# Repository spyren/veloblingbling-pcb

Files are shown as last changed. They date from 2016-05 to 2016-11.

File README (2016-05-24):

Electronic Design for the Velo Bling-Bling Project
**************************************************

http://veloblingbling.ch

LED lights for bicycle wheels.
16 multi color LEDs on each side (PCB top- and bottom side).
There are two windows (upper and lower) on each side for display dynamic
information like speed, trip time, trip distance, etc. or static information
like strings and images.

The Printed Circuit Board (PCB) is free hardware.
The PCB is a multi-layer (4 layer) 160 x 30.5 x 1.6 mm FR4 board.
The firmware for the MK22DX256VLF5 MCU is also on GitHub:
https://github.com/spyren/veloblingbling-mcu

There is also an optional Bluetooth Low Energy (Smart) subsystem on board.
It is a LAIRD BL600-SA module. The Bluetooth application software is on GitHub
too:
https://github.com/spyren/veloblingbling-ble

It is possible to mount die PCB direct onto the wheel spokes but it is better
to use a mounting frame. This frame can be ordered from http://shapeways.com
or you can print it by yourself on 3D printer.
https://github.com/spyren/veloblingbling-frame

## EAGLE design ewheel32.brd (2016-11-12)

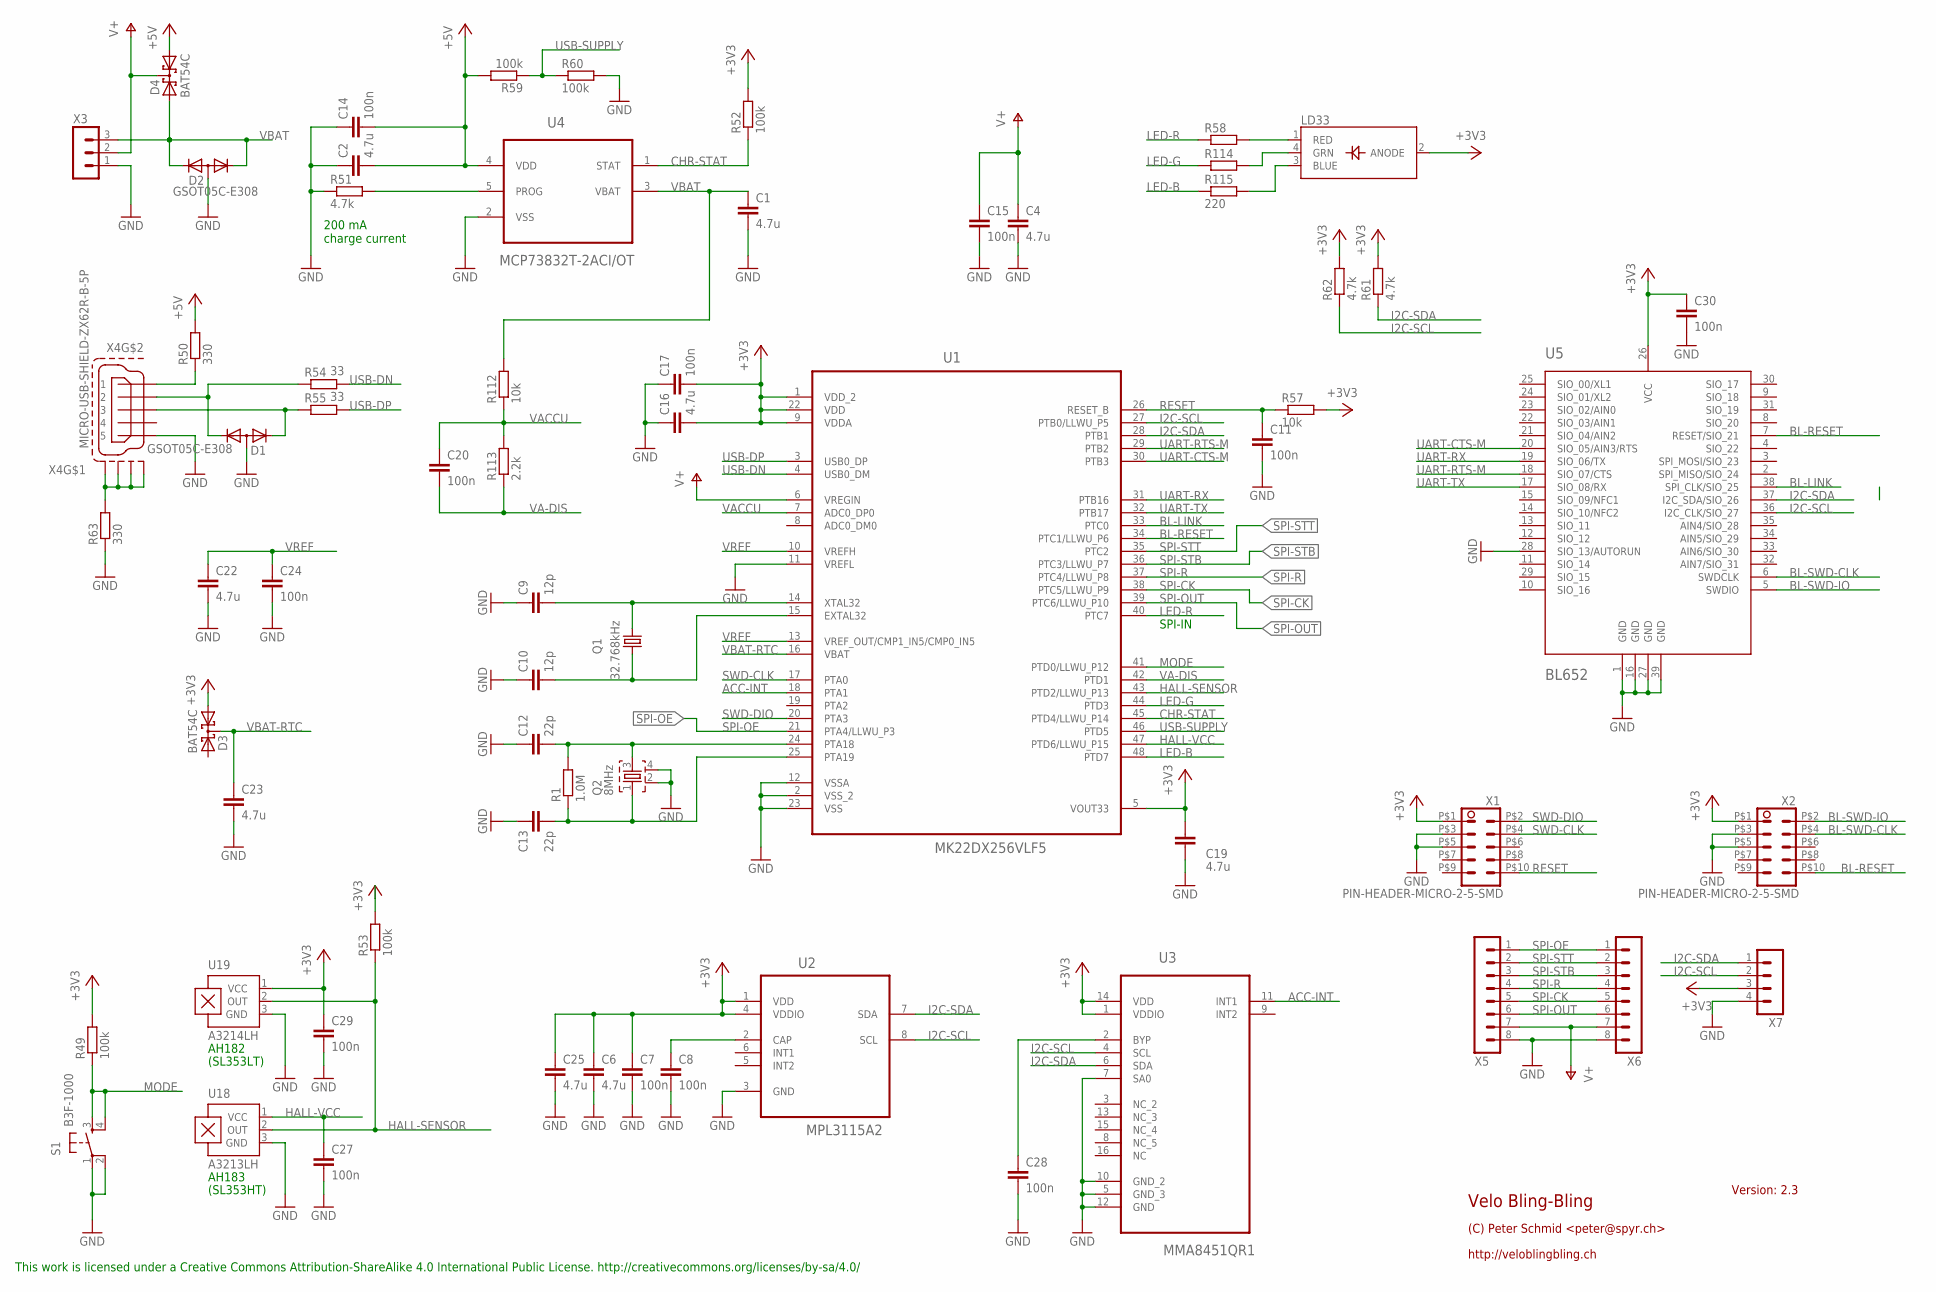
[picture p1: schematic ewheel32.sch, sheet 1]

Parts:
C1, C2, C4, C6, C16, C19, C22, C23, C25: 4.7u; C0805
C7, C8, C11, C14, C15, C17, C20, C24, C27, C28, C29, C30: 100n; C0805
C9, C10: 12p; C0805
C12, C13: 22p; C0805
D1, D2: GSOT05C-E308; SOT23
D3, D4: BAT54C; SOT23
LD33: CLV1A-FKB; RGBLED-PLCC4
Q1: 32.768kHz; ABS07
Q2: 8MHz; ABM3B
R1: 1.0M; R0805
R49, R52, R53, R59, R60: 100k; R0805
R50, R63: 330; R1206
R51, R61, R62: 4.7k; R0805
R54, R55: 33; R0805
R57, R112: 10k; R0805
R58, R114, R115: 220; R0805
R113: 2.2k; R0805
S1: B3F-1000; B3S-1000
U1: MK22DX256VLF5; QFP50P900X900X160-48N
U2: MPL3115A2; DFN300X500X120-8N
U3: MMA8451QR1; QFN50P300X300X100-16N
U4: MCP73832T-2ACI/OT; SOT95P280X145-5N
U5: BL652
U18: A3213LH; SOT23-W
U19: A3214LH; SOT23-W
X1, X2: PIN-HEADER-MICRO-2-5-SMD; PIN-HEADER-NICRO-2-5-SMD
X3: MA03-1
X4: MICRO-USB-SHIELD-ZX62R-B-5P; ZX62R-B-5P
X5, X6: MA08-1
X7: MA04-1

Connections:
+3V3: C6.1, C7.1, C16.2, C17.2, C19.1, C25.1, C29.1, C30.1, D3.1 (A1), LD33.2 (ANODE), R49.2, R52.2, R53.2, R57.2, R61.2, R62.2, U1.1 (VDD_2), U1.5 (VOUT33), U1.9 (VDDA), U1.22 (VDD), U2.1 (VDD), U2.4 (VDDIO), U3.1 (VDDIO), U3.14 (VDD), U5.26 (VCC), U19.1 (VCC), X1.P$1 (1), X2.P$1 (1), X7.3
+5V: C2.2, C14.2, D4.1 (A1), R50.2, R59.2, U4.4 (VDD)
ACC-INT: U1.18 (PTA1), U3.11 (INT1)
BL-LINK: U1.33 (PTC0), U5.38 (SPI_CLK/SIO_25)
BL-RESET: U1.34 (PTC1/LLWU_P6), U5.7 (RESET/SIO_21), X2.P$10 (10)
BL-SWD-CLK: U5.6 (SWDCLK), X2.P$4 (4)
BL-SWD-IO: U5.5 (SWDIO), X2.P$2 (2)
CHR-STAT: R52.1, U1.45 (PTD4/LLWU_P14), U4.1 (STAT)
GND: C1.2, C2.1, C4.2, C6.2, C7.2, C8.2, C9.1, C10.1, C11.2, C12.1, C13.1, C14.1, C15.2, C16.1, C17.1, C19.2, C22.2, C23.2, C24.2, C25.2, C27.2, C28.2, C29.2, C30.2, D1.3 (A), D2.3 (A), Q2.2, Q2.4, R51.1, R60.2, R63.1, S1.1, S1.2 (P1), U1.2 (VSS_2), U1.11 (VREFL), U1.12 (VSSA), U1.23 (VSS), U2.3 (GND), U3.5 (GND_3), U3.7 (SA0), U3.10 (GND_2), U3.12 (GND), U4.2 (VSS), U5.1 (GND), U5.16 (GND), U5.27 (GND), U5.28 (SIO_13/AUTORUN), U5.39 (GND), U18.3 (GND), U19.3 (GND), X1.P$3 (3), X1.P$5 (5), X2.P$3 (3), X2.P$5 (5), X3.1, X4.5, X5.8, X6.8, X7.4; also elsewhere on the board
HALL-SENSOR: R53.1, U1.43 (PTD2/LLWU_P13), U18.2 (OUT), U19.2 (OUT)
HALL-VCC: C27.1, U1.47 (PTD6/LLWU_P15), U18.1 (VCC)
I2C-SCL: R62.1, U1.27 (PTB0/LLWU_P5), U2.8 (SCL), U3.4 (SCL), U5.36 (I2C_CLK/SIO_27), X7.2
I2C-SDA: R61.1, U1.28 (PTB1), U2.7 (SDA), U3.6 (SDA), U5.37 (I2C_SDA/SIO_26), X7.1
LED-B: R115.1, U1.48 (PTD7)
LED-G: R114.1, U1.44 (PTD3)
LED-R: R58.1, U1.40 (PTC7)
MODE: R49.1, S1.3 (S), S1.4 (S1), U1.41 (PTD0/LLWU_P12)
unnamed: C12.2, Q2.3, R1.2, U1.24 (PTA18)
unnamed: C13.2, Q2.1, R1.1, U1.25 (PTA19)
unnamed: C28.1, U3.2 (BYP)
unnamed: R51.2, U4.5 (PROG)
unnamed: LD33.4 (GRN), R114.2
unnamed: LD33.1 (RED), R58.2
unnamed: LD33.3 (BLUE), R115.2
unnamed: R63.2, X4.M1 (S1), X4.M2 (S2), X4.M3 (S3), X4.M4 (S4)
unnamed: C8.1, U2.2 (CAP)
unnamed: R50.1, X4.1
unnamed: D1.1 (K1), R54.1, X4.2
unnamed: D1.2 (K2), R55.1, X4.3
unnamed: C9.2, Q1.P$2 (2), U1.14 (XTAL32)
unnamed: C10.2, Q1.P$1 (1), U1.15 (EXTAL32)
RESET: C11.1, R57.1, U1.26 (RESET_B), X1.P$10 (10)
SPI-CK: U1.38 (PTC5/LLWU_P9), X5.5, X6.5; also elsewhere on the board
SPI-OE: U1.21 (PTA4/LLWU_P3), X5.1, X6.1; also elsewhere on the board
SPI-OUT: U1.39 (PTC6/LLWU_P10), X5.6, X6.6; also elsewhere on the board
SPI-R: U1.37 (PTC4/LLWU_P8), X5.4, X6.4; also elsewhere on the board
SPI-STB: U1.36 (PTC3/LLWU_P7), X5.3, X6.3; also elsewhere on the board
SPI-STT: U1.35 (PTC2), X5.2, X6.2; also elsewhere on the board
SWD-CLK: U1.17 (PTA0), X1.P$4 (4)
SWD-DIO: U1.20 (PTA3), X1.P$2 (2)
UART-CTS-M: U1.30 (PTB3), U5.20 (SIO_05/AIN3/RTS)
UART-RTS-M: U1.29 (PTB2), U5.18 (SIO_07/CTS)
UART-RX: U1.31 (PTB16), U5.19 (SIO_06/TX)
UART-TX: U1.32 (PTB17), U5.17 (SIO_08/RX)
USB-DN: R54.2, U1.4 (USB0_DM)
USB-DP: R55.2, U1.3 (USB0_DP)
USB-SUPPLY: R59.1, R60.1, U1.46 (PTD5)
V+: C4.1, C15.1, D4.3 (CC), U1.6 (VREGIN), X3.2, X5.7, X6.7; also elsewhere on the board
VA-DIS: C20.2, R113.1, U1.42 (PTD1)
VACCU: C20.1, R112.1, R113.2, U1.7 (ADC0_DP0)
VBAT: C1.1, D2.1 (K1), D2.2 (K2), D4.2 (A2), R112.2, U4.3 (VBAT), X3.3
VBAT-RTC: C23.1, D3.3 (CC), U1.16 (VBAT)
VREF: C22.1, C24.1, U1.10 (VREFH), U1.13 (VREF_OUT/CMP1_IN5/CMP0_IN5)

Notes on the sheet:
200 mA charge current
SPI-IN
(SL353LT)
(SL353HT)
AH182
AH183

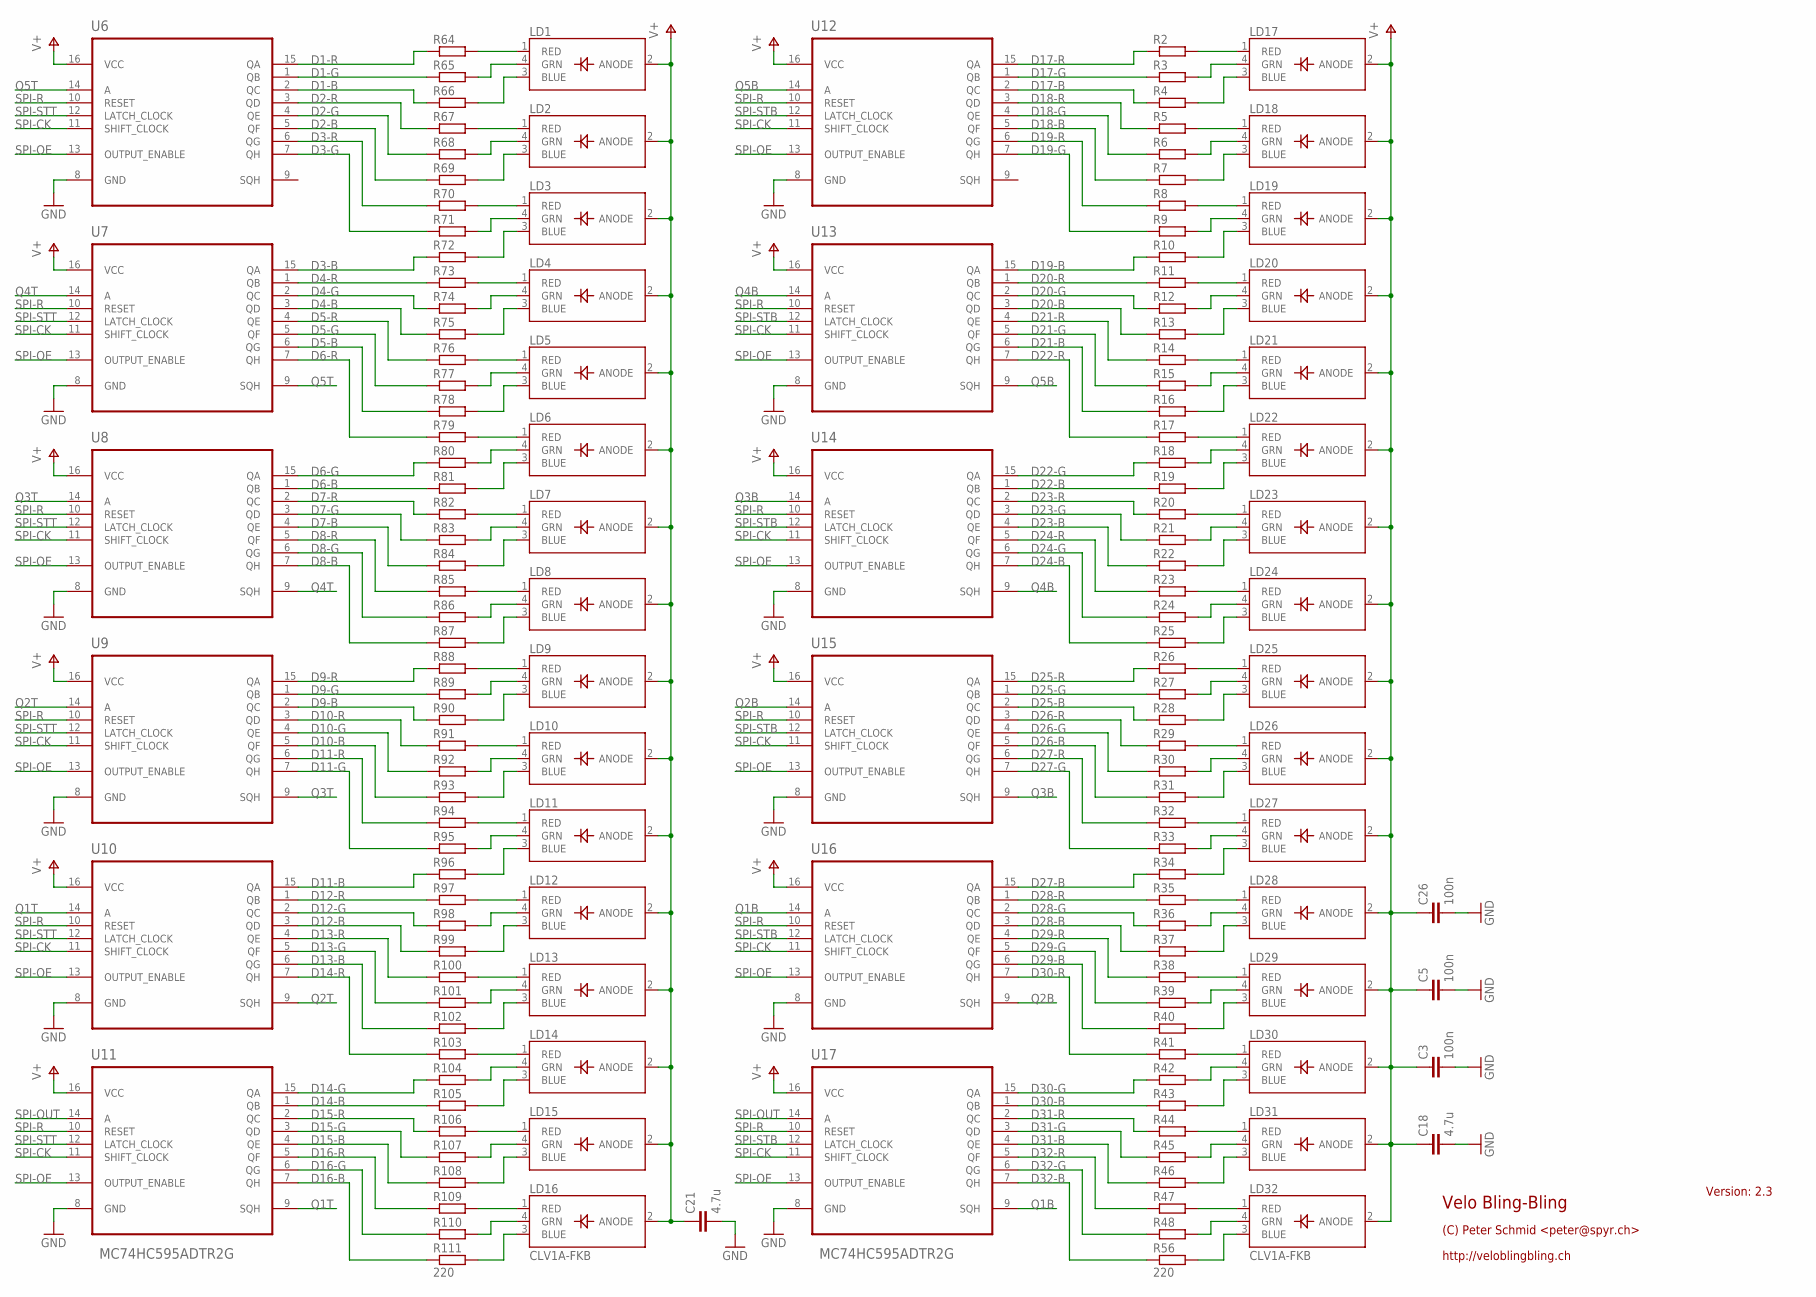
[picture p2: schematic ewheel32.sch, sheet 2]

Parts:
C3, C5, C26: 100n; C0805
C18, C21: 4.7u; C0805
LD1, LD2, LD3, LD4, LD5, LD6, LD7, LD8, LD9, LD10, LD11, LD12, LD13, LD14, LD15, LD16, LD17, LD18, LD19, LD20, LD21, LD22, LD23, LD24, LD25, LD26, LD27, LD28, LD29, LD30, LD31, LD32: CLV1A-FKB; RGBLED-PLCC4
R2, R3, R4, R5, R6, R7, R8, R9, R10, R11, R12, R13, R14, R15, R16, R17, R18, R19, R20, R21, R22, R23, R24, R25, R26, R27, R28, R29, R30, R31, R32, R33, R34, R35, R36, R37, R38, R39, R40, R41, R42, R43, R44, R45, R46, R47, R48, R56, R64, R65, R66, R67, R68, R69, R70, R71, R72, R73, R74, R75, R76, R77, R78, R79, R80, R81, R82, R83, R84, R85, R86, R87, R88, R89, R90, R91, R92, R93, R94, R95, R96, R97, R98, R99, R100, R101, R102, R103, R104, R105, R106, R107, R108, R109, R110, R111: 220; R0805
U6, U7, U8, U9, U10, U11, U12, U13, U14, U15, U16, U17: MC74HC595ADTR2G; SOP65P640X120-16N

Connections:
D1-B: R66.1, U6.2 (QC)
D1-G: R65.1, U6.1 (QB)
D1-R: R64.1, U6.15 (QA)
D2-B: R69.1, U6.5 (QF)
D2-G: R68.1, U6.4 (QE)
D2-R: R67.1, U6.3 (QD)
D3-B: R72.1, U7.15 (QA)
D3-G: R71.1, U6.7 (QH)
D3-R: R70.1, U6.6 (QG)
D4-B: R75.1, U7.3 (QD)
D4-G: R74.1, U7.2 (QC)
D4-R: R73.1, U7.1 (QB)
D5-B: R78.1, U7.6 (QG)
D5-G: R77.1, U7.5 (QF)
D5-R: R76.1, U7.4 (QE)
D6-B: R81.1, U8.1 (QB)
D6-G: R80.1, U8.15 (QA)
D6-R: R79.1, U7.7 (QH)
D7-B: R84.1, U8.4 (QE)
D7-G: R83.1, U8.3 (QD)
D7-R: R82.1, U8.2 (QC)
D8-B: R87.1, U8.7 (QH)
D8-G: R86.1, U8.6 (QG)
D8-R: R85.1, U8.5 (QF)
D9-B: R90.1, U9.2 (QC)
D9-G: R89.1, U9.1 (QB)
D9-R: R88.1, U9.15 (QA)
D10-B: R93.1, U9.5 (QF)
D10-G: R92.1, U9.4 (QE)
D10-R: R91.1, U9.3 (QD)
D11-B: R96.1, U10.15 (QA)
D11-G: R95.1, U9.7 (QH)
D11-R: R94.1, U9.6 (QG)
D12-B: R99.1, U10.3 (QD)
D12-G: R98.1, U10.2 (QC)
D12-R: R97.1, U10.1 (QB)
D13-B: R102.1, U10.6 (QG)
D13-G: R101.1, U10.5 (QF)
D13-R: R100.1, U10.4 (QE)
D14-B: R105.1, U11.1 (QB)
D14-G: R104.1, U11.15 (QA)
D14-R: R103.1, U10.7 (QH)
D15-B: R108.1, U11.4 (QE)
D15-G: R107.1, U11.3 (QD)
D15-R: R106.1, U11.2 (QC)
D16-B: R111.1, U11.7 (QH)
D16-G: R110.1, U11.6 (QG)
D16-R: R109.1, U11.5 (QF)
D17-B: R4.1, U12.2 (QC)
D17-G: R3.1, U12.1 (QB)
D17-R: R2.1, U12.15 (QA)
D18-B: R7.1, U12.5 (QF)
D18-G: R6.1, U12.4 (QE)
D18-R: R5.1, U12.3 (QD)
D19-B: R10.1, U13.15 (QA)
D19-G: R9.1, U12.7 (QH)
D19-R: R8.1, U12.6 (QG)
D20-B: R13.1, U13.3 (QD)
D20-G: R12.1, U13.2 (QC)
D20-R: R11.1, U13.1 (QB)
D21-B: R16.1, U13.6 (QG)
D21-G: R15.1, U13.5 (QF)
D21-R: R14.1, U13.4 (QE)
D22-B: R19.1, U14.1 (QB)
D22-G: R18.1, U14.15 (QA)
D22-R: R17.1, U13.7 (QH)
D23-B: R22.1, U14.4 (QE)
D23-G: R21.1, U14.3 (QD)
D23-R: R20.1, U14.2 (QC)
D24-B: R25.1, U14.7 (QH)
D24-G: R24.1, U14.6 (QG)
D24-R: R23.1, U14.5 (QF)
D25-B: R28.1, U15.2 (QC)
D25-G: R27.1, U15.1 (QB)
D25-R: R26.1, U15.15 (QA)
D26-B: R31.1, U15.5 (QF)
D26-G: R30.1, U15.4 (QE)
D26-R: R29.1, U15.3 (QD)
D27-B: R34.1, U16.15 (QA)
D27-G: R33.1, U15.7 (QH)
D27-R: R32.1, U15.6 (QG)
D28-B: R37.1, U16.3 (QD)
D28-G: R36.1, U16.2 (QC)
D28-R: R35.1, U16.1 (QB)
D29-B: R40.1, U16.6 (QG)
D29-G: R39.1, U16.5 (QF)
D29-R: R38.1, U16.4 (QE)
D30-B: R43.1, U17.1 (QB)
D30-G: R42.1, U17.15 (QA)
D30-R: R41.1, U16.7 (QH)
D31-B: R46.1, U17.4 (QE)
D31-G: R45.1, U17.3 (QD)
D31-R: R44.1, U17.2 (QC)
D32-B: R56.1, U17.7 (QH)
D32-G: R48.1, U17.6 (QG)
D32-R: R47.1, U17.5 (QF)
GND: C3.2, C5.2, C18.2, C21.2, C26.2, U6.8 (GND), U7.8 (GND), U8.8 (GND), U9.8 (GND), U10.8 (GND), U11.8 (GND), U12.8 (GND), U13.8 (GND), U14.8 (GND), U15.8 (GND), U16.8 (GND), U17.8 (GND); also elsewhere on the board
unnamed: LD17.4 (GRN), R3.2
unnamed: LD17.1 (RED), R2.2
unnamed: LD17.3 (BLUE), R4.2
unnamed: LD18.4 (GRN), R6.2
unnamed: LD18.1 (RED), R5.2
unnamed: LD18.3 (BLUE), R7.2
unnamed: LD19.4 (GRN), R9.2
unnamed: LD19.1 (RED), R8.2
unnamed: LD19.3 (BLUE), R10.2
unnamed: LD20.4 (GRN), R12.2
unnamed: LD20.1 (RED), R11.2
unnamed: LD20.3 (BLUE), R13.2
unnamed: LD21.4 (GRN), R15.2
unnamed: LD21.1 (RED), R14.2
unnamed: LD21.3 (BLUE), R16.2
unnamed: LD22.4 (GRN), R18.2
unnamed: LD22.1 (RED), R17.2
unnamed: LD22.3 (BLUE), R19.2
unnamed: LD23.4 (GRN), R21.2
unnamed: LD23.1 (RED), R20.2
unnamed: LD23.3 (BLUE), R22.2
unnamed: LD24.4 (GRN), R24.2
unnamed: LD24.1 (RED), R23.2
unnamed: LD24.3 (BLUE), R25.2
unnamed: LD25.4 (GRN), R27.2
unnamed: LD25.1 (RED), R26.2
unnamed: LD25.3 (BLUE), R28.2
unnamed: LD26.4 (GRN), R30.2
unnamed: LD26.1 (RED), R29.2
unnamed: LD26.3 (BLUE), R31.2
unnamed: LD27.4 (GRN), R33.2
unnamed: LD27.1 (RED), R32.2
unnamed: LD27.3 (BLUE), R34.2
unnamed: LD28.4 (GRN), R36.2
unnamed: LD28.1 (RED), R35.2
unnamed: LD1.4 (GRN), R65.2
unnamed: LD1.1 (RED), R64.2
unnamed: LD1.3 (BLUE), R66.2
unnamed: LD2.4 (GRN), R68.2
unnamed: LD2.1 (RED), R67.2
unnamed: LD2.3 (BLUE), R69.2
unnamed: LD3.4 (GRN), R71.2
unnamed: LD3.1 (RED), R70.2
unnamed: LD3.3 (BLUE), R72.2
unnamed: LD4.4 (GRN), R74.2
unnamed: LD4.1 (RED), R73.2
unnamed: LD4.3 (BLUE), R75.2
unnamed: LD5.4 (GRN), R77.2
unnamed: LD5.1 (RED), R76.2
unnamed: LD5.3 (BLUE), R78.2
unnamed: LD6.4 (GRN), R80.2
unnamed: LD6.1 (RED), R79.2
unnamed: LD6.3 (BLUE), R81.2
unnamed: LD7.4 (GRN), R83.2
unnamed: LD7.1 (RED), R82.2
unnamed: LD7.3 (BLUE), R84.2
unnamed: LD8.4 (GRN), R86.2
unnamed: LD8.1 (RED), R85.2
unnamed: LD8.3 (BLUE), R87.2
unnamed: LD9.4 (GRN), R89.2
unnamed: LD9.1 (RED), R88.2
unnamed: LD9.3 (BLUE), R90.2
unnamed: LD10.4 (GRN), R92.2
unnamed: LD10.1 (RED), R91.2
unnamed: LD10.3 (BLUE), R93.2
unnamed: LD11.4 (GRN), R95.2
unnamed: LD11.1 (RED), R94.2
unnamed: LD11.3 (BLUE), R96.2
unnamed: LD12.4 (GRN), R98.2
unnamed: LD12.1 (RED), R97.2
unnamed: LD12.3 (BLUE), R99.2
unnamed: LD13.4 (GRN), R101.2
unnamed: LD13.1 (RED), R100.2
unnamed: LD13.3 (BLUE), R102.2
unnamed: LD14.4 (GRN), R104.2
unnamed: LD14.1 (RED), R103.2
unnamed: LD14.3 (BLUE), R105.2
unnamed: LD15.4 (GRN), R107.2
unnamed: LD15.1 (RED), R106.2
unnamed: LD15.3 (BLUE), R108.2
unnamed: LD16.4 (GRN), R110.2
unnamed: LD16.1 (RED), R109.2
unnamed: LD16.3 (BLUE), R111.2
unnamed: LD28.3 (BLUE), R37.2
unnamed: LD29.4 (GRN), R39.2
unnamed: LD29.1 (RED), R38.2
unnamed: LD29.3 (BLUE), R40.2
unnamed: LD30.4 (GRN), R42.2
unnamed: LD30.1 (RED), R41.2
unnamed: LD30.3 (BLUE), R43.2
unnamed: LD31.4 (GRN), R45.2
unnamed: LD31.1 (RED), R44.2
unnamed: LD31.3 (BLUE), R46.2
unnamed: LD32.4 (GRN), R48.2
unnamed: LD32.1 (RED), R47.2
unnamed: LD32.3 (BLUE), R56.2
Q1B: U16.14 (A), U17.9 (SQH)
Q1T: U10.14 (A), U11.9 (SQH)
Q2B: U15.14 (A), U16.9 (SQH)
Q2T: U9.14 (A), U10.9 (SQH)
Q3B: U14.14 (A), U15.9 (SQH)
Q3T: U8.14 (A), U9.9 (SQH)
Q4B: U13.14 (A), U14.9 (SQH)
Q4T: U7.14 (A), U8.9 (SQH)
Q5B: U12.14 (A), U13.9 (SQH)
Q5T: U6.14 (A), U7.9 (SQH)
SPI-CK: U6.11 (SHIFT_CLOCK), U7.11 (SHIFT_CLOCK), U8.11 (SHIFT_CLOCK), U9.11 (SHIFT_CLOCK), U10.11 (SHIFT_CLOCK), U11.11 (SHIFT_CLOCK), U12.11 (SHIFT_CLOCK), U13.11 (SHIFT_CLOCK), U14.11 (SHIFT_CLOCK), U15.11 (SHIFT_CLOCK), U16.11 (SHIFT_CLOCK), U17.11 (SHIFT_CLOCK); also elsewhere on the board
SPI-OE: U6.13 (OUTPUT_ENABLE), U7.13 (OUTPUT_ENABLE), U8.13 (OUTPUT_ENABLE), U9.13 (OUTPUT_ENABLE), U10.13 (OUTPUT_ENABLE), U11.13 (OUTPUT_ENABLE), U12.13 (OUTPUT_ENABLE), U13.13 (OUTPUT_ENABLE), U14.13 (OUTPUT_ENABLE), U15.13 (OUTPUT_ENABLE), U16.13 (OUTPUT_ENABLE), U17.13 (OUTPUT_ENABLE); also elsewhere on the board
SPI-OUT: U11.14 (A), U17.14 (A); also elsewhere on the board
SPI-R: U6.10 (RESET), U7.10 (RESET), U8.10 (RESET), U9.10 (RESET), U10.10 (RESET), U11.10 (RESET), U12.10 (RESET), U13.10 (RESET), U14.10 (RESET), U15.10 (RESET), U16.10 (RESET), U17.10 (RESET); also elsewhere on the board
SPI-STB: U12.12 (LATCH_CLOCK), U13.12 (LATCH_CLOCK), U14.12 (LATCH_CLOCK), U15.12 (LATCH_CLOCK), U16.12 (LATCH_CLOCK), U17.12 (LATCH_CLOCK); also elsewhere on the board
SPI-STT: U6.12 (LATCH_CLOCK), U7.12 (LATCH_CLOCK), U8.12 (LATCH_CLOCK), U9.12 (LATCH_CLOCK), U10.12 (LATCH_CLOCK), U11.12 (LATCH_CLOCK); also elsewhere on the board
V+: C3.1, C5.1, C18.1, C21.1, C26.1, LD1.2 (ANODE), LD2.2 (ANODE), LD3.2 (ANODE), LD4.2 (ANODE), LD5.2 (ANODE), LD6.2 (ANODE), LD7.2 (ANODE), LD8.2 (ANODE), LD9.2 (ANODE), LD10.2 (ANODE), LD11.2 (ANODE), LD12.2 (ANODE), LD13.2 (ANODE), LD14.2 (ANODE), LD15.2 (ANODE), LD16.2 (ANODE), LD17.2 (ANODE), LD18.2 (ANODE), LD19.2 (ANODE), LD20.2 (ANODE), LD21.2 (ANODE), LD22.2 (ANODE), LD23.2 (ANODE), LD24.2 (ANODE), LD25.2 (ANODE), LD26.2 (ANODE), LD27.2 (ANODE), LD28.2 (ANODE), LD29.2 (ANODE), LD30.2 (ANODE), LD31.2 (ANODE), LD32.2 (ANODE), U6.16 (VCC), U7.16 (VCC), U8.16 (VCC), U9.16 (VCC), U10.16 (VCC), U11.16 (VCC), U12.16 (VCC), U13.16 (VCC), U14.16 (VCC), U15.16 (VCC), U16.16 (VCC), U17.16 (VCC); also elsewhere on the board

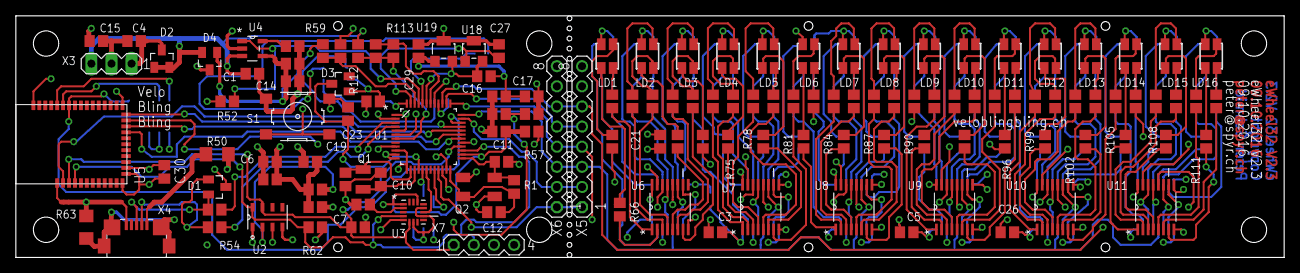
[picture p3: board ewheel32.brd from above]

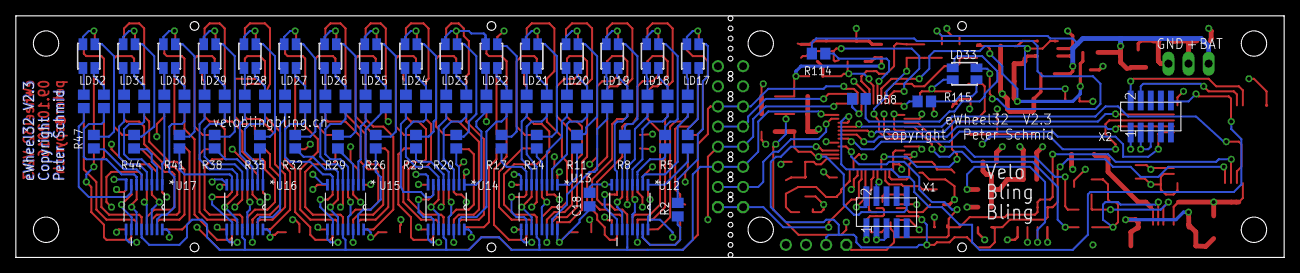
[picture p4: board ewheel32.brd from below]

Board: 4 copper layers, 160.0 x 30.5 mm, 211 parts (77 on the bottom side), 255 nets.

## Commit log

2015-09-23 Version 1.3, Betatest
    [ewheel32.brd, ewheel32.sch]
2015-10-06 Schottky diode for charger
    [ewheel32.brd, ewheel32.sch]
2016-05-23 Intermediate version. Do not use.
    [ewheel32.brd, ewheel32.sch]
2016-05-23 Version 1.4. BAT/VCC connector wrong.
    [ewheel32.brd, ewheel32.sch]
2016-05-23 VBAT and V+ are fixed.
    [ewheel32.brd, ewheel32.sch]
2016-05-24 README and LICENSE added.
    [ewheel32.brd]
2016-07-11 State RGB LED. Second Hall Sensor (ultra low power to wake up from deep sleep). Breakable PCB (MCU part / LED part). Pin head for I2C and SPI.
    [ewheel32.brd, ewheel32.sch]
2016-11-12 New Bluetooth Low Energy module BL652
    [ewheel32.brd, ewheel32.sch]

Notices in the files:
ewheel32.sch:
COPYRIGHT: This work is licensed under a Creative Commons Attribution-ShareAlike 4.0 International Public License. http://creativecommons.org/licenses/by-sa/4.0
